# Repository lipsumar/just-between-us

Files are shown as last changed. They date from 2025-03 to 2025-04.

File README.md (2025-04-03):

# Just Between Us

Just Between Us is a eurorack clock module heavily inspired by Pam's New Workout.

I made this module for 2 main reasons:

1. I like modular but my wallet likes it much less
2. I want to learn more about electronics and C++

This is my second large Arduino project and still consider myself a C++ and electronics noob. Keep in mind information in this repo may be inexact. I would absolutely love to be corrected on any mistake made in this project, please do get in touch! piremmanuel at gmail dot com

## Features

- 2 analog outputs (more can be added very easily)
- MIDI clock (USB)
- Play/pause button
- Rotary encoder
- OLED display (128x64)
- User interface
  - Set BPM
  - Set modifier for each output (x1, x2, x3, /2, /3, /4, ...)
  - Parameters for each output:
    - Wave (square, triangle, sine) ([in progress](https://github.com/lipsumar/just-between-us/discussions/2))
    - Width (duty cycle)
    - Phase

This is the very first version of this module, the prototype stage really. Analog outputs are currently limited to gates and only 2 parameters are implemented (width & phase).

## User interface

Again, borrowing heavily from Pam's New Workout.

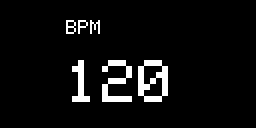
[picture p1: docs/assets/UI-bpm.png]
UI - bpm

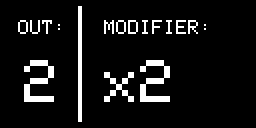
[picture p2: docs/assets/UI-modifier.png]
UI - modifier

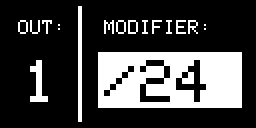
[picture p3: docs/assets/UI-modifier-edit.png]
UI - modifier edit

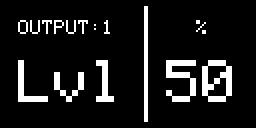
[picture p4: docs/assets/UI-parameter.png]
UI - parameter


## Schematic

The full schematics can be found in the `docs/` folder:

- [PDF](./docs/schematic.pdf)
- [KiCad](./docs/JustBetweenUs.kicad_sch)

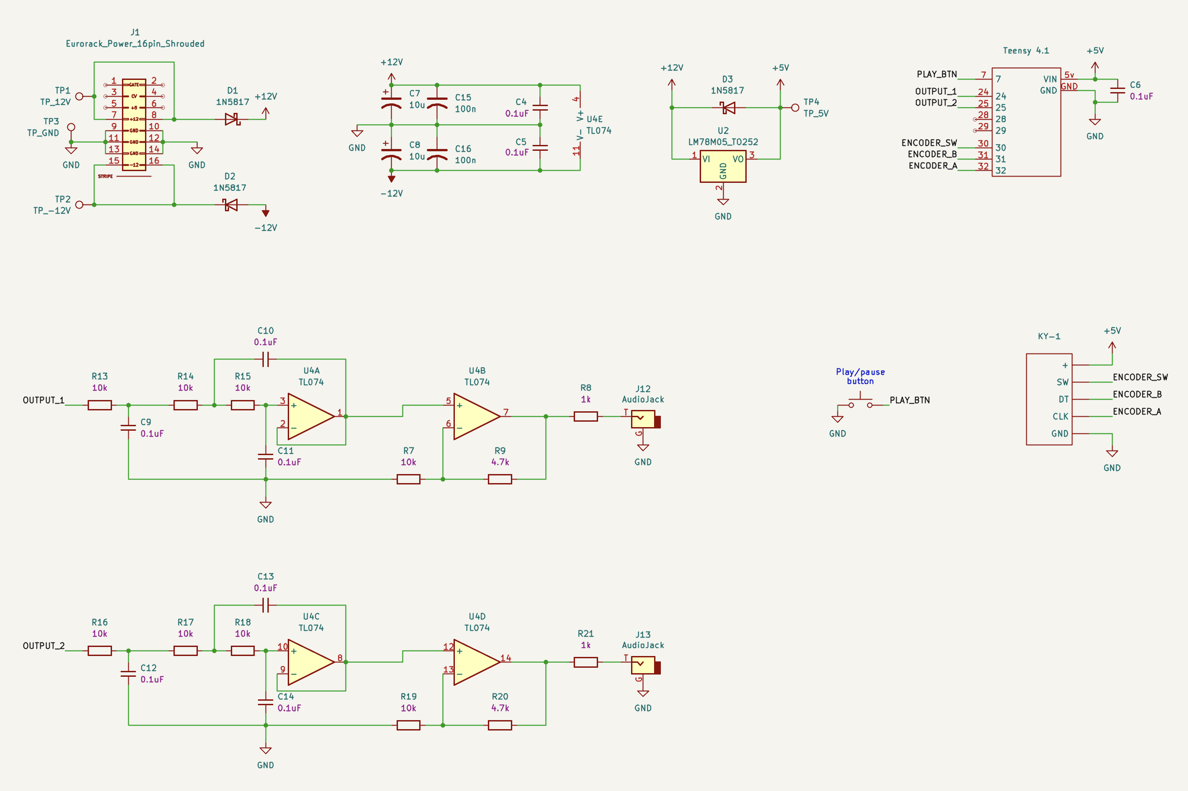
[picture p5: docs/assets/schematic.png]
Full Schematic


There is no PCB yet, as this is still on breadboard at the moment.

## Details and comments

### Teensy

This module is based on a Teensy 4.1. A Teensy may be oversized for such a project, but I had one lying around and wanted to get to know the Teensy.

The experience was great, the documentation too. I never regretted this choice. I particularly enjoyed details such as being able to rename the MIDI device easily.

### Output stage

I'm currently working on getting proper analog outputs: https://github.com/lipsumar/just-between-us/discussions/2

### Power

#### USB and external power

Do not plug USB with the Teensy powerd through eurorack. I'm currently using a cable with the + cable cut out. Eventually a second USB port will allow to connect safely to a USB host but without the +5v connection.

Here is an excellent page about this very topic: https://www.pjrc.com/teensy/external_power.html

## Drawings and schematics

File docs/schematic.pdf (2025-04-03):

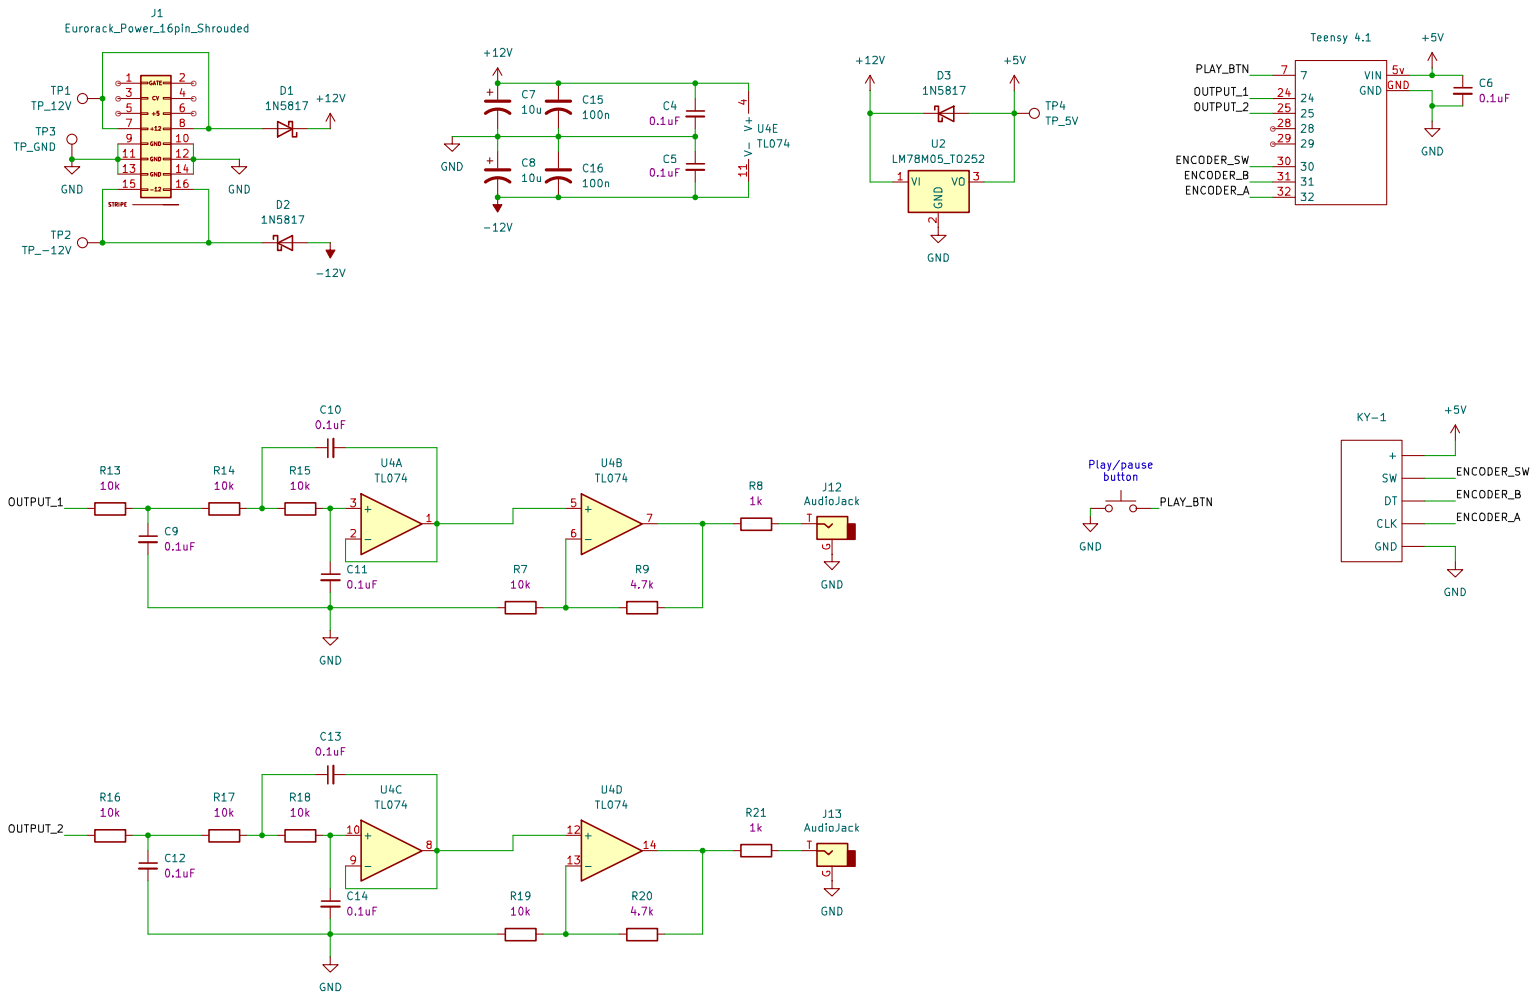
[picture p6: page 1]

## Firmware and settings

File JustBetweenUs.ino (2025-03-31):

#include <Bounce.h>
#include "./src/GlobalState/GlobalState.h"
#include "./src/MidiClock/MidiClock.h"
#include "./src/RotaryEncoder/RotaryEncoder.h"
#include "./src/MasterClock/MasterClock.h"
#include "./src/UiDisplay/UiDisplay.h"
#include "./src/UiState/UiState.h"
#include "./src/Waveform/Square.h"
#include "./src/Waveform/Triangle.h"
#include "./src/Waveform/Sine.h"

// pins
#define PIN_BTN 7
#define PIN_ENCODER_A 32
#define PIN_ENCODER_B 31
#define PIN_ENCODER_BTN 30
// pins - output pins
#define PIN_OUTPUT_1 24
#define PIN_OUTPUT_2 25
#define NUM_OUTPUTS 2
// this array also defines output index for the state
const int outputPins[NUM_OUTPUTS] = { PIN_OUTPUT_1, PIN_OUTPUT_2 };

// PWM config
// see https://www.pjrc.com/teensy/td_pulse.html
#define PWM_FREQUENCY 36621
#define PWM_RESOLUTION 12
#define PWM_MAX_VALUE ((1 << PWM_RESOLUTION) - 1)  // 2^12 - 1 = 4095

// state stuff
GlobalState state;
UiState uiState(state.getBpm(), state.getOutputSize());

// display stuff
UiDisplay display;

// clocks
const unsigned int CLOCK_PPQ = 192;
MasterClock masterClock(CLOCK_PPQ, state.getBpm(), 8);  // 8 quarter per cycle - the largest divider in modifiers
MidiClock midiClock(CLOCK_PPQ);

// controls
Bounce pushButton(PIN_BTN, 10);  // 10ms debounce
RotaryEncoder knob(PIN_ENCODER_A, PIN_ENCODER_B);
Bounce knobButton(PIN_ENCODER_BTN, 10);
unsigned int knobButtonPressedAt = 0;
bool knobButtonDown = false;

void setup() {
  Serial.begin(9600);
  Serial.println("Just Betwen Us - setup begin");

  // configure pins
  pinMode(PIN_BTN, INPUT_PULLUP);
  pinMode(PIN_ENCODER_BTN, INPUT_PULLUP);

  // configure PWM output pins & register them in state
  analogWriteResolution(PWM_RESOLUTION);
  for(int i=0; i<NUM_OUTPUTS; i++){
    pinMode(outputPins[i], OUTPUT);
    analogWriteFrequency(outputPins[i], PWM_FREQUENCY);
    analogWrite(outputPins[i], 0);

    state.setOutputPin(i, outputPins[i]);
  }


  display.init();

  masterClock.setUserCallback(masterClockTick);

  display.update(state, uiState);
  delay(2000);
  uiState.setMode(UiState::Mode::BPM);
  display.update(state, uiState);
}

void loop() {

  // controls & state update

  knob.update();
  int direction = knob.hasTurned();
  if (direction) {
    uiState.turn(direction, state);
  }

  if (knobButton.update()) {
    if (knobButton.fallingEdge()) {  // press
      knobButtonPressedAt = millis();
      knobButtonDown = true;
    }
    if (knobButton.risingEdge()) {  // release
      knobButtonDown = false;
      unsigned int pressTimeMs = millis() - knobButtonPressedAt;
      if (pressTimeMs < 800) {
        uiState.click(state);
      }
    }
  }
  if (knobButtonDown && millis() - knobButtonPressedAt > 800) {
    uiState.longClick(state);
    knobButtonDown = false;  // this isn't true but we need it to avoid longClick looping
  }

  if (pushButton.update()) {
    if (pushButton.fallingEdge()) {
      state.togglePlayPause();
    }
  }

  // reacting to state change

  if (state.hasPlayingChanged()) {
    if (state.isPlaying()) {
      masterClock.start();
      midiClock.start();
    } else {
      masterClock.stop();
      midiClock.stop();
    }
  }

  if (state.hasBpmChanged()) {
    masterClock.setBpm(state.getBpm());
  }

  bool stateDirty = state.checkDirtyAndReset();
  bool uiStateDirty = uiState.checkDirtyAndReset();
  if (stateDirty || uiStateDirty) {
    display.update(state, uiState);
  }
}

// !! This is an interrupt
void masterClockTick(unsigned int clockTickCount) {
  midiClock.update(clockTickCount);

  for (unsigned int outputIndex = 0; outputIndex < state.getOutputSize(); outputIndex++) {
    OutputState output = state.getOutputReadOnly(outputIndex);

    float value;
    switch(ParamaterWave::ALL_WAVES[output.getWave()].type){
      case ParamaterWave::Type::SQUARE:
        value = squareWave(clockTickCount, CLOCK_PPQ, output.getPeriodInQuarters(), output.getWidth(), output.getPhase());
        break;
      case ParamaterWave::Type::TRIANGLE:
        value = triangleWave(clockTickCount, CLOCK_PPQ, output.getPeriodInQuarters(), output.getWidth(), output.getPhase());
        break;
      case ParamaterWave::Type::SINE:
        value = sineWave(clockTickCount, CLOCK_PPQ, output.getPeriodInQuarters(), output.getWidth(), output.getPhase());
        break;
    }

    unsigned int pin = output.getPin();

    analogWrite(pin, value * PWM_MAX_VALUE);
  }
}

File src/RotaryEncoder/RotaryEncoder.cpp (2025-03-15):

// RotaryEncoder.cpp
#include "RotaryEncoder.h"

RotaryEncoder::RotaryEncoder(uint8_t pinA, uint8_t pinB)
  : knob(pinA, pinB) // Proper initialization
{
  // Additional setup if needed
}

void RotaryEncoder::update() {
  int rawValue = knob.read();
  
  // Check if the value is at a stable position (multiple of encoderMultiple)
  if (rawValue % encoderMultiple == 0) {
    // Only process if we're at a new stable position
    if (rawValue != lastStableValue) {
      // Calculate direction: -1 for left, 1 for right
      if (rawValue > lastStableValue) {
        lastDirection = 1; // Turned right
      } else {
        lastDirection = -1; // Turned left
      }
      
      // Save the new stable position
      lastStableValue = rawValue;
      
      // Update the step value
      currentStep = rawValue / encoderMultiple;
    } else {
      // At a stable position but no change
      lastDirection = 0;
    }
  } else {
    // We're between detents, no change to report
    lastDirection = 0;
  }
}

int RotaryEncoder::hasTurned() {
  // Returns direction of turn: -1 (left), 0 (no change), 1 (right)
  return lastDirection;
}

int RotaryEncoder::getCurrentStep() {
  // Return the current step position
  return currentStep;
}

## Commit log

2025-03-31 update schematics
    [JustBetweenUs.kicad_sch]
2025-04-02 cleanup kicad file
    [JustBetweenUs.kicad_sch]
2025-04-03 Insert power layout by @8sevenCentral
    [JustBetweenUs.kicad_sch]
